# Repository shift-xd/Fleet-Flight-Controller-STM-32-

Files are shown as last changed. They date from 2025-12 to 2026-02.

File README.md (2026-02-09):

# Fleet~Flight Controller

Compact STM32F405-based flight controller • Made for Hack Club Blueprint  

https://blueprint.hackclub.com/projects/5724

bg

Like this cat flying a plane fleet will fly your drones easily !

## Features
- STM32F405RGT6 (168 MHz, 1 MB Flash)
- 8 × PWM servo outputs (JST-SM)
- MPU-9250 / ICM-42688 ready (I2C + SPI)
- W25Q128 16 MB flash for blackbox
- USB-C (DFU + serial)
- 5 V buck + 3.3 V LDO (7–20 V input)
- 4 × M3 chamfered mounting holes
- 50.8 × 50.8 mm, 2-layer

## Images 
| Front PCB | Back PCB |
|---|---|
|  |  |

| Schematic | KiCad PCB Preview |
|---|---|
|  |  |

## Enclosure (New Addition)
Screenshot From 2025-12-13 14-02-03

## Files
- Added Schematics 
- Added the Gerber's 
- Added PCb files 
- Added Images 
- Yea that's pretty much it 

## Quick Flash
Hold BOOT button → plug USB

MIT License • Fork it, build it, fly it!  
Made with love by tHEYcALLmE-aLBIN

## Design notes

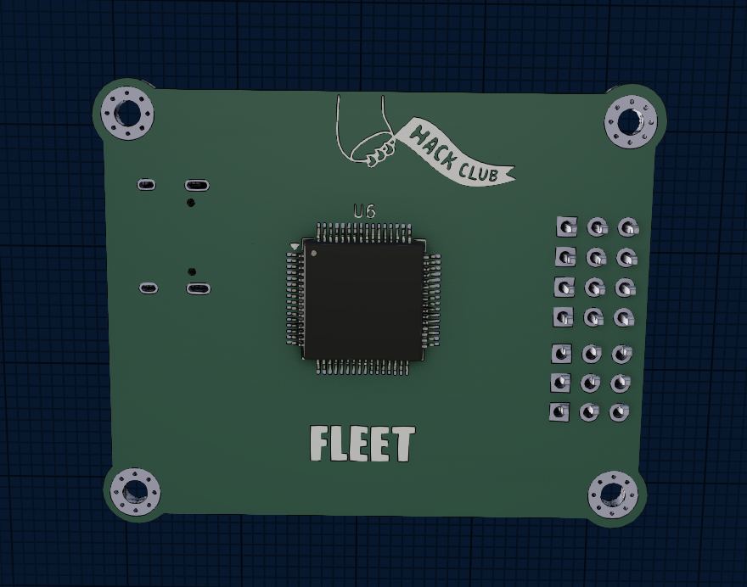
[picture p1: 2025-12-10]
2).Images/PCB /Fleet PCB Back Side .png

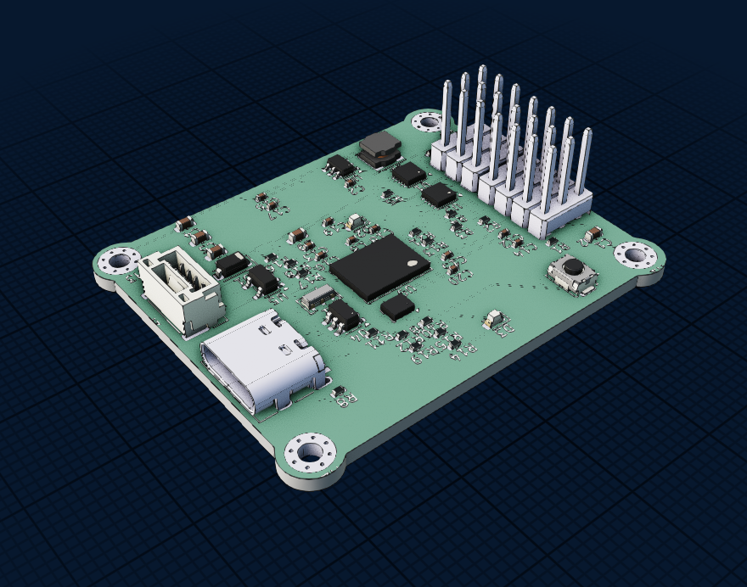
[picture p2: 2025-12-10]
2).Images/PCB /Fleet PCB Front .png

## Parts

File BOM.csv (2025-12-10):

Item | Designator | Value / Description | Footprint | Qty | LCSC Part # | LCSC Link | Unit Price | Total Price
----------------------------------- | ------------------------------------- | ----------------------------------- | ------------------------------- | ----- | --------------- | -------------------------------------------------------------------------------------------------------- | ------------ | -------------
MCU | U1 | STM32F405RGT6 | LQFP-64 | 1 | C2291636 | https://lcsc.com/product-detail/STM32F4_STM32F405RGT6_C2291636.html | $5.20 | $5.20
SPI Flash | U2 | W25Q128JVSIQ | SOIC-8 | 1 | C128667 | https://lcsc.com/product-detail/SPI-FLASH_Winbond-W25Q128JVSIQ_C128667.html | $0.79 | $0.79
5V Buck Converter | U3 | MP1584EN-LF-Z | SOIC-8 | 1 | C133123 | https://lcsc.com/product-detail/DC-DC_MPS-MP1584EN-LF-Z_C133123.html | $0.44 | $0.44
3.3V LDO | U4 | AMS1117-3.3 | SOT-223 | 1 | C6188 | https://lcsc.com/product-detail/LDO_AMS1117-3.3_C6188.html | $0.09 | $0.09
Crystal | Y1 | 8.000 MHz | HC-49S | 1 | C18520 | https://lcsc.com/product-detail/Crystals_8MHz_C18520.html | $0.12 | $0.12
Decoupling caps | C1–C10,C16–C20 | 0.1 µF X7R 50V | 0805 | 15 | C49683 | https://lcsc.com/product-detail/MLCC_0.1uF-50V-X7R_C49683.html | $0.01 | $0.15
Crystal load caps | C11,C12 | 22 pF NP0 | 0603 | 2 | C1350 | https://lcsc.com/product-detail/MLCC_22pF_C1350.html | $0.01 | $0.02
Input cap | C13 | 100 µF 25V | Radial 6.3×11 | 1 | C135336 | https://lcsc.com/product-detail/Elec-Cap_100uF-25V_C135336.html | $0.18 | $0.18
USB caps | C14,C15 | 27 pF NP0 | 0603 | 2 | C1883 | https://lcsc.com/product-detail/MLCC_27pF_C1883.html | $0.01 | $0.02
Pull-ups / LED resistor | R1–R7,R21 | 4.7 kΩ | 0805 | 8 | C25804 | https://lcsc.com/product-detail/Resistor_4.7k_C25804.html | $0.01 | $0.08
VBAT divider | R8,R9 | 10 kΩ | 0805 | 2 | C21109 | https://lcsc.com/product-detail/Resistor_10k_C21109.html | $0.01 | $0.02
Servo series resistors | R10–R17 | 100 Ω | 0805 | 8 | C25801 | https://lcsc.com/product-detail/Resistor_100R_C25801.html | $0.01 | $0.08
USB CC resistors | R18–R20 | 5.1 kΩ | 0603 | 3 | C17217 | https://lcsc.com/product-detail/Resistor_5.1k_C17217.html | $0.01 | $0.03
LED current limit | R22 | 330 Ω | 0805 | 1 | C25803 | https://lcsc.com/product-detail/Resistor_330R_C25803.html | $0.01 | $0.01
Power LED | D1 | Green 0805 | 0805 | 1 | C72041 | https://lcsc.com/product-detail/LED_Green-0805_C72041.html | $0.04 | $0.04
Status LED | D2 | Red 0805 | 0805 | 1 | C72043 | https://lcsc.com/product-detail/LED_Red-0805_C72043.html | $0.04 | $0.04
TVS diode | D3 | SMAJ24A | SMA | 1 | C285961 | https://lcsc.com/product-detail/TVS_SMAJ24A_C285961.html | $0.16 | $0.16
Ferrite bead | FB1 | BLM21PG600SN1D | 0805 | 1 | C85845 | https://lcsc.com/product-detail/Ferrite_BLM21PG600SN1D_C85845.html | $0.04 | $0.04
Sensor headers | J1–J3 | B2B-PH-K-S (2-pin) | JST PH | 3 | C49206 | https://lcsc.com/product-detail/JST-PH_B2B-PH-K-S_C49206.html | $0.12 | $0.36
Servo outputs | J4–J11 | S3B-PH-K-S (3-pin) | JST PH | 8 | C160404 | https://lcsc.com/product-detail/JST-PH_S3B-PH-K-S_C160404.html | $0.18 | $1.44
Telemetry port | J12 | S4B-PH-K-S (4-pin) | JST PH | 1 | C160405 | https://lcsc.com/product-detail/JST-PH_S4B-PH-K-S_C160405.html | $0.22 | $0.22
Power input | J13 | XT60PW-M (PCB male) | XT60 | 1 | C318970 | https://lcsc.com/product-detail/XT60PW-M_C318970.html | $0.68 | $0.68
USB-C receptacle | J14 | USB4105-GF-A | USB-C 16-pin | 1 | C165948 | https://lcsc.com/product-detail/USB-C_GCT-USB4105-GF-A_C165948.html | $0.59 | $0.59
Boot button | SW1 | TL3340AF160QG | 6×6 mm tactile | 1 | C318884 | https://lcsc.com/product-detail/Tactile_TL3340AF160QG_C318884.html | $0.14 | $0.14
Mounting holes | H1–H4 | M3 chamfered | MountingHole 3.2 mm | 4 | – | – | – | –
**Components subtotal** |  |  |  |  |  |  |  | **$11.94**
**PCB fabrication (5 pcs, JLCPCB)** |  | 2-layer, green, HASL/ENIG | 50.8 × 50.8 mm | 5 | – | https://jlcpcb.com | – | **$20.00**
**Shipping (worldwide)** |  |  |  |  | – | – | – | **$30.00**
**Grand total (5 boards)** |  |  |  |  |  |  |  | **$61.94**
**Cost per board** |  |  |  |  |  |  |  | **~$12.39**

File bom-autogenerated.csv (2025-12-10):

Id | Designator | Footprint | Quantity | Designation | Supplier and ref
1 | C14,C17,C18,C12,C15,C13,C16,C2,C19,C10 | C_0402_1005Metric | 10 | 100n
2 | R14,R10,R13,R15,R12,R11 | R_0402_1005Metric | 6 | 10k
3 | R21,R17,R16 | R_0402_1005Metric | 3 | 22
4 | H1,H2,H3,H4 | MountingHole_2.2mm_M2_Pad_Via | 4 | MountingHole
5 | C20 | C_0402_1005Metric | 1 | 4.7u
6 | C8 | C_0402_1005Metric | 1 | 2.2u
7 | C4,C3 | C_0603_1608Metric | 2 | 22u
8 | U2 | TSOT-23-6 | 1 | AP63205WU
9 | L1 | L_Vishay_IFSC-1515AH_4x4x1.8mm | 1 | CSME0418D-4R7M-LRH
10 | R5,R6,R2,R3,R1,R4 | R_0402_1005Metric | 6 | 470
11 | U5 | SOT-23-5 | 1 | XC6220B331MR
12 | R8,R9 | R_0402_1005Metric | 2 | 5.1k
13 | U4 | SOT-23-6 | 1 | USBLC6-2SC6
14 | U3,U1 | DFN-10-1EP_2.6x2.6mm_P0.5mm_EP1.3x2.2mm | 2 | ESD1014
15 | D2 | LED_0603_1608Metric | 1 | Green
16 | J2 | 7xServo_Vertical | 1 | Outputs
17 | R19 | R_0402_1005Metric | 1 | 47
18 | C9,C5,C1 | C_0603_1608Metric | 3 | 10u
19 | C11 | C_0402_1005Metric | 1 | 1u
20 | R18 | R_0402_1005Metric | 1 | 75
21 | U8 | Bosch_LGA-8_2x2.5mm_P0.65mm_ClockwisePinNumbering | 1 | SPL06-001
22 | J1 | USB_C_Receptacle_HRO_TYPE-C-31-M-12 | 1 | USB_C_Receptacle_USB2.0
23 | D3 | LED_0603_1608Metric | 1 | Red
24 | J3 | JST_GH_BM04B-GHS-TBT_1x04-1MP_P1.25mm_Vertical | 1 | A
25 | D1 | D_SOD-123 | 1 | B5819W_C8598
26 | U9 | WSON-8-1EP_8x6mm_P1.27mm_EP3.4x4.3mm | 1 | W25N01G
27 | SW1 | SW_Push_SPST_NO_Alps_SKRK | 1 | SW_Push
28 | R7 | R_0402_1005Metric | 1 | 22r
29 | Y1 | Resonator_SMD_Murata_CSTxExxV-3Pin_3.0x1.1mm | 1 | 8MHz
30 | U6 | LQFP-64_10x10mm_P0.5mm | 1 | STM32F722RETx

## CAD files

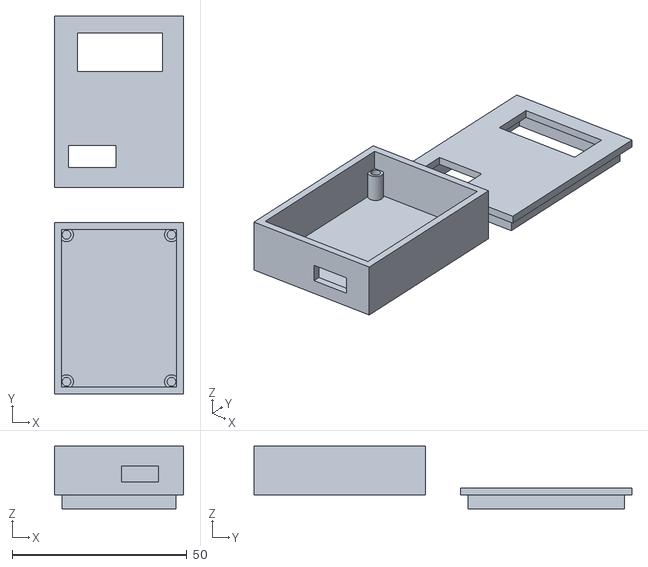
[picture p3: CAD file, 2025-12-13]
3).3d Casing ( Maybe )/Fleet enclosure .stl
37.0 x 108.0 x 18.0

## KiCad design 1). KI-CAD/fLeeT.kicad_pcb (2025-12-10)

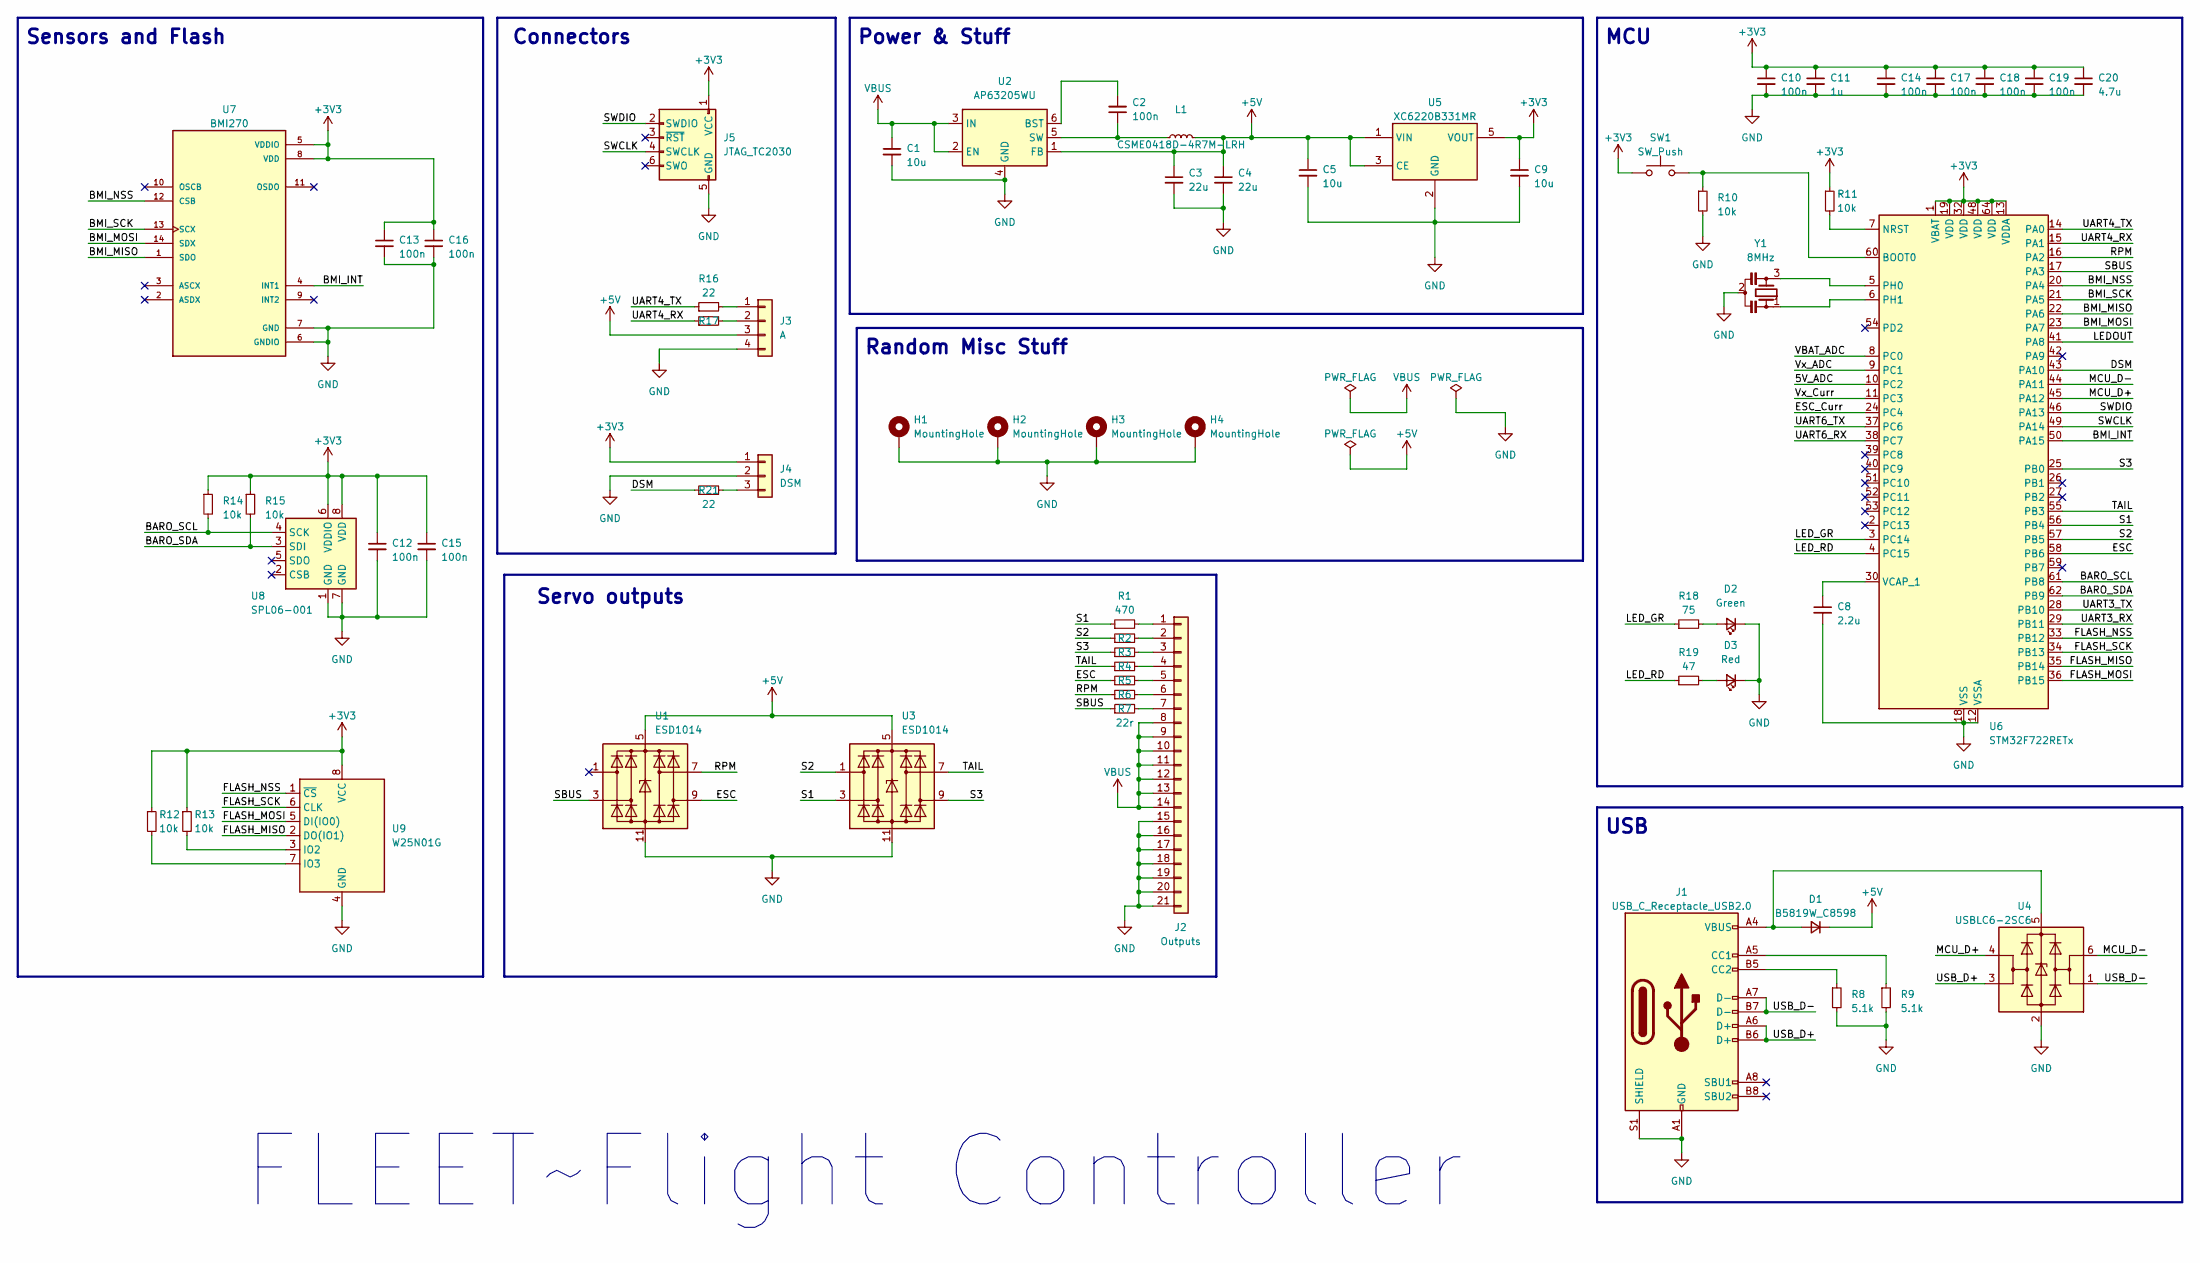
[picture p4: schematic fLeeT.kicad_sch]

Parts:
C1, C5, C9: 10u; C_0603_1608Metric
C2, C10, C12, C13, C14, C15, C16, C17, C18, C19: 100n; C_0402_1005Metric
C3, C4: 22u; C_0603_1608Metric
C8: 2.2u; C_0402_1005Metric
C11: 1u; C_0402_1005Metric
C20: 4.7u; C_0402_1005Metric
D1: B5819W_C8598; D_SOD-123
D2: Green; LED_0603_1608Metric
D3: Red; LED_0603_1608Metric
H1, H2, H3, H4: MountingHole; MountingHole_2.2mm_M2_Pad_Via
J1: USB_C_Receptacle_USB2.0; USB_C_Receptacle_HRO_TYPE-C-31-M-12
J2: Outputs; 7xServo_Vertical
J3: A; JST_GH_BM04B-GHS-TBT_1x04-1MP_P1.25mm_Vertical
J4: DSM; JST_ZH_B3B-ZR_1x03_P1.50mm_Vertical
J5: JTAG_TC2030; CON_TC2030_outlined
L1: CSME0418D-4R7M-LRH; L_Vishay_IFSC-1515AH_4x4x1.8mm
R1, R2, R3, R4, R5, R6: 470; R_0402_1005Metric
R7: 22r; R_0402_1005Metric
R8, R9: 5.1k; R_0402_1005Metric
R10, R11, R12, R13, R14, R15: 10k; R_0402_1005Metric
R16, R17, R21: 22; R_0402_1005Metric
R18: 75; R_0402_1005Metric
R19: 47; R_0402_1005Metric
SW1: SW_Push; SW_Push_SPST_NO_Alps_SKRK
U1, U3: ESD1014; DFN-10-1EP_2.6x2.6mm_P0.5mm_EP1.3x2.2mm
U2: AP63205WU; TSOT-23-6
U4: USBLC6-2SC6; SOT-23-6
U5: XC6220B331MR; SOT-23-5
U6: STM32F722RETx; LQFP-64_10x10mm_P0.5mm
U7: BMI270; XDCR_BMI270
U8: SPL06-001; Bosch_LGA-8_2x2.5mm_P0.65mm_ClockwisePinNumbering
U9: W25N01G; WSON-8-1EP_8x6mm_P1.27mm_EP3.4x4.3mm
Y1: 8MHz; Resonator_SMD_Murata_CSTxExxV-3Pin_3.0x1.1mm

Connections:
+3V3: C9.1, C10.1, C11.1, C12.1, C13.1, C14.1, C15.1, C16.1, C17.1, C18.1, C19.1, C20.1, J4.1, J5.1 (VCC), R11.1, R12.1, R13.1, R14.1, R15.1, SW1.1, U5.5 (VOUT), U6.1 (VBAT), U6.13 (VDDA), U6.19 (VDD), U6.32 (VDD), U6.48 (VDD), U6.64 (VDD), U7.5 (VDDIO), U7.8 (VDD), U8.6 (VDDIO), U8.8 (VDD), U9.8 (VCC)
+5V: C3.1, C4.1, C5.1, D1.1 (K), J3.3, L1.2, U1.5 (VBUS), U2.1 (FB), U3.5 (VBUS), U5.1 (VIN), U5.3 (CE)
/5V_ADC: U6.10 (PC2)
/BARO_SCL: R14.2, U6.61 (PB8), U8.4 (SCK)
/BARO_SDA: R15.2, U6.62 (PB9), U8.3 (SDI)
/BMI_INT: U6.50 (PA15), U7.4 (INT1)
/BMI_MISO: U6.22 (PA6), U7.1 (SDO)
/BMI_MOSI: U6.23 (PA7), U7.14 (SDX)
/BMI_NSS: U6.20 (PA4), U7.12 (CSB)
/BMI_SCK: U6.21 (PA5), U7.13 (SCX)
/DSM: R21.1, U6.43 (PA10)
/ESC: R5.1, U1.9 (I/O4), U6.58 (PB6)
/ESC_Curr: U6.24 (PC4)
/FLASH_MISO: U6.35 (PB14), U9.2 (DO(IO1))
/FLASH_MOSI: U6.36 (PB15), U9.5 (DI(IO0))
/FLASH_NSS: U6.33 (PB12), U9.1 (~CS)
/FLASH_SCK: U6.34 (PB13), U9.6 (CLK)
/LEDOUT: U6.41 (PA8)
/LED_GR: R18.1, U6.3 (PC14)
/LED_RD: R19.1, U6.4 (PC15)
/MCU_D+: U4.4 (I/O2), U6.45 (PA12)
/MCU_D-: U4.6 (I/O1), U6.44 (PA11)
/RPM: R6.1, U1.7 (I/O3), U6.16 (PA2)
/S1: R1.1, U3.3 (I/O2), U6.56 (PB4)
/S2: R2.1, U3.1 (I/O1), U6.57 (PB5)
/S3: R3.1, U3.9 (I/O4), U6.25 (PB0)
/SBUS: R7.1, U1.3 (I/O2), U6.17 (PA3)
/SWCLK: J5.4 (SWCLK), U6.49 (PA14)
/SWDIO: J5.2 (SWDIO), U6.46 (PA13)
/TAIL: R4.1, U3.7 (I/O3), U6.55 (PB3)
/UART3_RX: U6.29 (PB11)
/UART3_TX: U6.28 (PB10)
/UART4_RX: R17.1, U6.15 (PA1)
/UART4_TX: R16.1, U6.14 (PA0)
/UART6_RX: U6.38 (PC7)
/UART6_TX: U6.37 (PC6)
/USB_D+: J1.A6 (D+), J1.B6 (D+), U4.3 (I/O2)
/USB_D-: J1.A7 (D-), J1.B7 (D-), U4.1 (I/O1)
/VBAT_ADC: U6.8 (PC0)
/Vx_ADC: U6.9 (PC1)
/Vx_Curr: U6.11 (PC3)
GND: C1.2, C3.2, C4.2, C5.2, C8.2, C9.2, C10.2, C11.2, C12.2, C13.2, C14.2, C15.2, C16.2, C17.2, C18.2, C19.2, C20.2, D2.1 (K), D3.1 (K), H1.1, H2.1, H3.1, H4.1, J1.A1 (GND), J1.A12 (GND), J1.B1 (GND), J1.B12 (GND), J1.S1 (SHIELD), J2.15, J2.16, J2.17, J2.18, J2.19, J2.20, J2.21, J3.4, J4.2, J5.5 (GND), R8.2, R9.2, R10.2, U1.11 (GND), U2.4 (GND), U3.11 (GND), U4.2 (GND), U5.2 (GND), U6.12 (VSSA), U6.18 (VSS), U6.31 (VSS), U6.47 (VSS), U6.63 (VSS), U7.6 (GNDIO), U7.7 (GND), U8.1 (GND), U8.7 (GND), U9.4 (GND), Y1.2
unnamed: D1.2 (A), J1.A4 (VBUS), J1.A9 (VBUS), J1.B4 (VBUS), J1.B9 (VBUS), U4.5 (VBUS)
unnamed: D2.2 (A), R18.2
unnamed: D3.2 (A), R19.2
unnamed: J1.A5 (CC1), R9.1
unnamed: J1.B5 (CC2), R8.1
unnamed: J2.1, R1.2
unnamed: J2.2, R2.2
unnamed: J2.3, R3.2
unnamed: J2.4, R4.2
unnamed: J2.5, R5.2
unnamed: J2.6, R6.2
unnamed: J2.7, R7.2
unnamed: J3.1, R16.2
unnamed: J3.2, R17.2
unnamed: J4.3, R21.2
unnamed: C2.2, U2.6 (BST)
unnamed: C2.1, L1.1, U2.5 (SW)
unnamed: R10.1, SW1.2, U6.60 (BOOT0)
unnamed: R11.2, U6.7 (NRST)
unnamed: U6.5 (PH0), Y1.3
unnamed: U6.6 (PH1), Y1.1
unnamed: C8.1, U6.30 (VCAP_1)
unnamed: R13.2, U9.3 (IO2)
unnamed: R12.2, U9.7 (IO3)
VBUS: C1.1, J2.8, J2.9, J2.10, J2.11, J2.12, J2.13, J2.14, U2.2 (EN), U2.3 (IN)

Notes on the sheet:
USB
MCU
Connectors
Random Misc Stuff
Servo outputs
Sensors and Flash
Power & Stuff
FLEET~Flight Controller

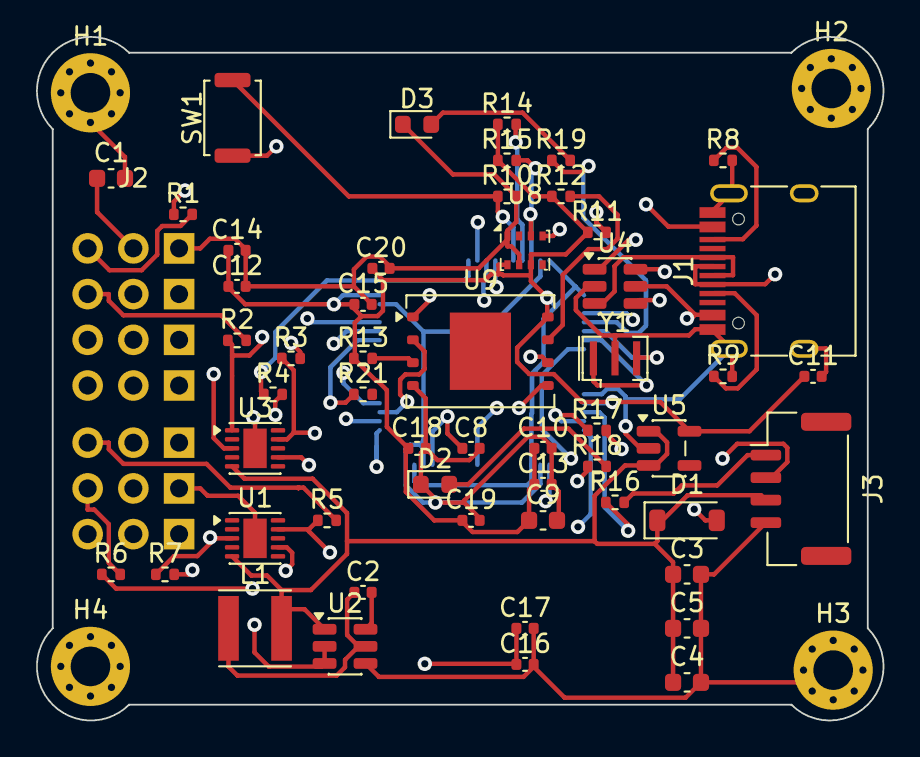
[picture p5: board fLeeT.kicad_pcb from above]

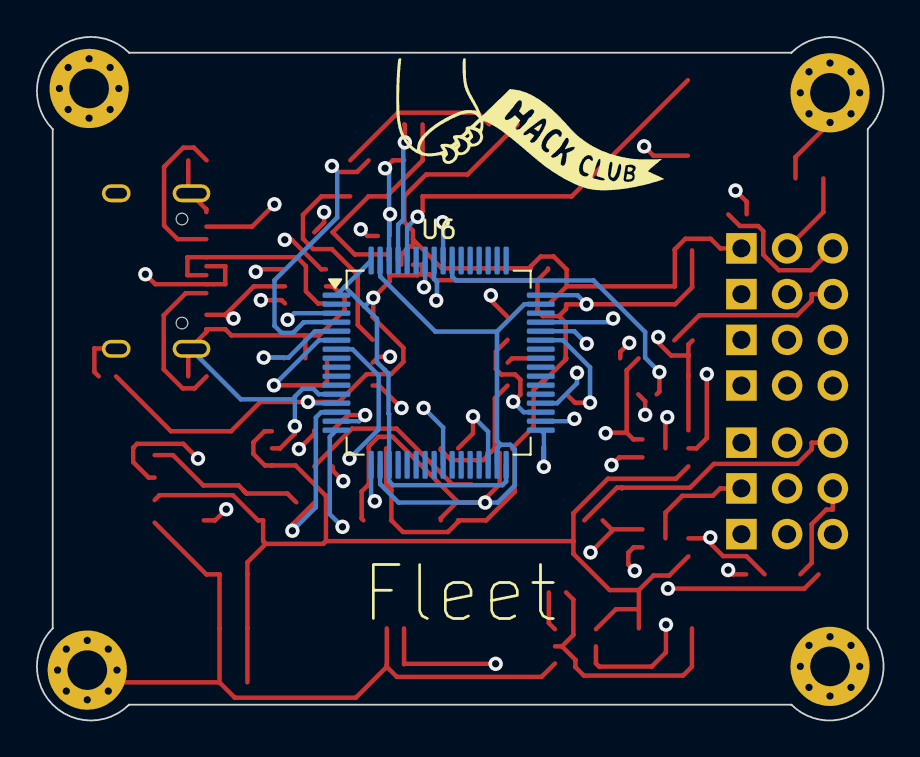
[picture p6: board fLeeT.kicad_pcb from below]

Board: 2 copper layers, 47.0 x 38.0 mm, 60 parts (2 on the bottom side), 49 nets.

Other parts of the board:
': LOGO

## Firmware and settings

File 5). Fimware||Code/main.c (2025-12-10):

#include <stdint.h>
#include "board.h"
#include "hal_init.h"
#include "mpu6000.h"
#include "madgwick.h"
#include "pid.h"
#include "pwm_out.h"
#include "uart.h"

volatile uint32_t systick_ms = 0;
void SysTick_Handler(void){ systick_ms++; }

int main(void){
    HAL_Init();
    SystemClock_Config();
    board_init();
    hal_init();
    uart_init();
    pwm_out_init();
    mpu_init();
    madgwick_init();
    pid_init_defaults();

    uint32_t last = systick_ms;
    while(1){
        if ((systick_ms - last) >= 1){
            last = systick_ms;
            sensor_data_t s = mpu_read();
            madgwick_update(s.gx,s.gy,s.gz,s.ax,s.ay,s.az, 0.001f);
            euler_t e = madgwick_get_euler();
            rc_frame_t rc = {0}; // stub - replace with real RC read
            control_output_t out = attitude_control_step(e, rc);
            float motor[4];
            mixer_mix(out, motor);
            pwm_out_write(motor);
            uart_telemetry_send(e, rc);
        }
    }
    return 0;
}

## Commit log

2025-12-10 For BLu-Print Commit
    [fLeeT.kicad_pcb, fLeeT.kicad_sch]
2025-12-13 Added Enclosure #d model
    [Fleet enclosure .stl]
